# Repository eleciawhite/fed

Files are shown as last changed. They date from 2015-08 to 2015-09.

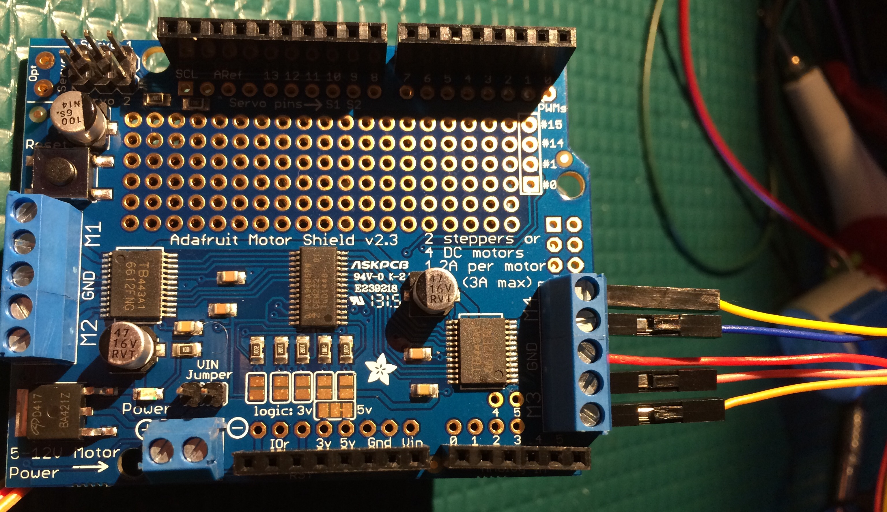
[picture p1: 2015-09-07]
doc/photos/motorShieldConnections.JPG

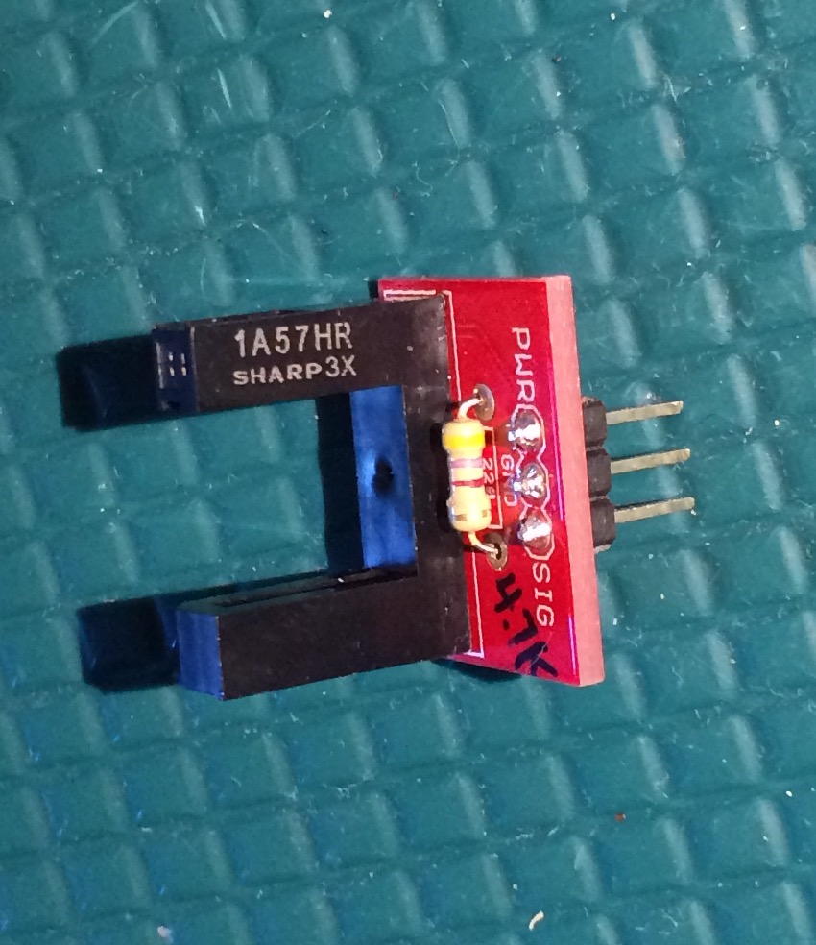
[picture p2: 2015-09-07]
doc/photos/irPhotoInterrupter.JPG

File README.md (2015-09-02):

# fed
Food Experimentation Device for precision feeding of mice. The system uses an Arduino processor, 
servo motor, IR beam detector, and SD card to log pellets taken. FED runs off of a battery. 

Please see the wiki page for more information, including build instructions: https://github.com/eleciawhite/fed/wiki

The hardware directory contains the system schematics. 
The mechanical pieces can be found on TinkerCAD (https://www.tinkercad.com/users/69Zt0NRn4eA-katrina-nguyen).
The software is in fed-arduino.

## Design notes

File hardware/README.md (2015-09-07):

Note that the FED schematics do not currently show the motor shield that is being used by the software.

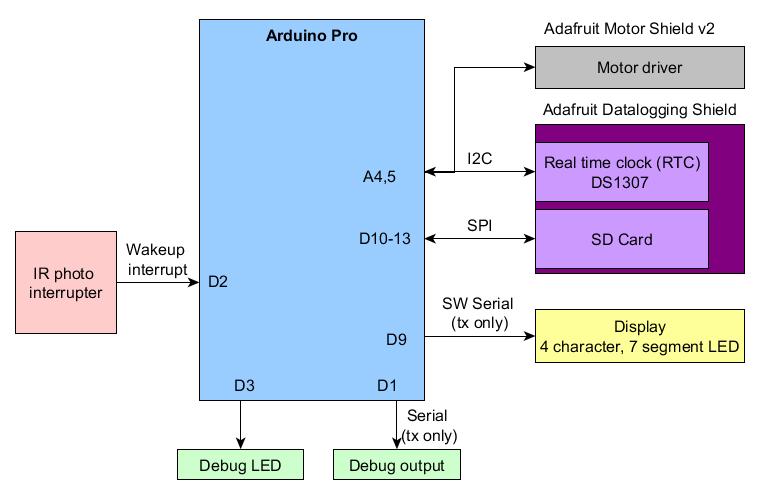
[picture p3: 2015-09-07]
doc/arduino-software-architecture.jpg

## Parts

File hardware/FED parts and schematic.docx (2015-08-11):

Electronics

1. Arduino Uno
2. Data logging shield for Arduino (Adafruit)
3. Small reduction stepper motor – 5VDC 32-step 1/16 gearing (Adafruit)
4. Dual h-bridge motor driver for DC or steppers – 600mA – L293D
5. Photo Interrupter board with GP1A57HRJ00f (Karlsson Robotics)
  a. GP1A57HRJ00f sensor (SHARP)
6. 7-segment serial display (SparkFun)

Circuit Schematic

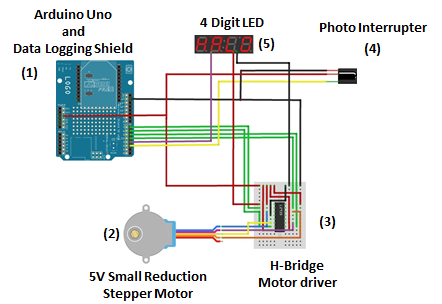
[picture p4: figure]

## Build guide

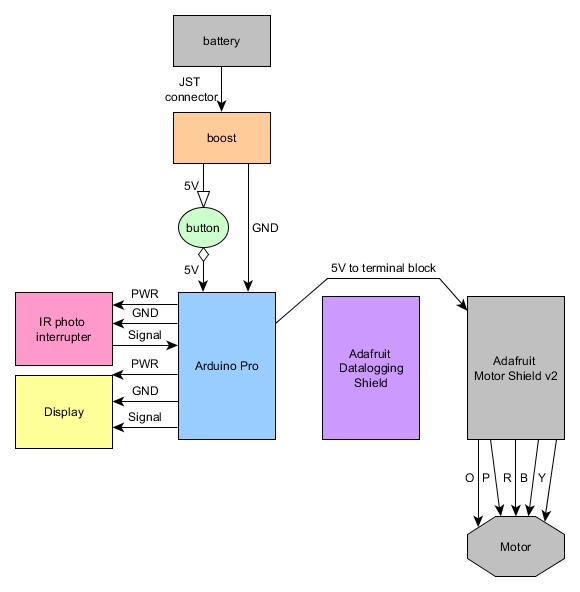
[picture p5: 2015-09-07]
doc/arduino-wiring-connection.jpg

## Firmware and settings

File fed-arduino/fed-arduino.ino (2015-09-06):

#include <avr/sleep.h>
#include <avr/power.h>
#include <avr/wdt.h>
#include <SdFat.h>                // SD and RTC libraries
#include "RTClib.h"
#include <Wire.h>
#include <SPI.h>
#include <Adafruit_GFX.h>
#include <Adafruit_SharpMem.h>
#include <avr/interrupt.h>
#include <avr/io.h>
#include <SoftwareSerial.h>
#include <Adafruit_MotorShield.h>
#include "utility/Adafruit_PWMServoDriver.h"

#define FILENAME "PELLET_Cage12.csv"

#define DISPLAY_SERIAL_RX_PIN 255 // we don't need a receive pin, 255 indicates this
// Connect the Arduino pin 3 to the rx pin on the 7 segment display
#define DISPLAY_SERIAL_TX_PIN 9

// Photo interrupter is also the wakeup for the system
#define PHOTO_INTERRUPTER_PIN 2

SoftwareSerial LEDserial = SoftwareSerial(DISPLAY_SERIAL_RX_PIN, DISPLAY_SERIAL_TX_PIN);
SdFat SD;

long previousMillis = 0;
long startTime = 0;
long timeElapsed = 0;
const long day2 = 86400000; // 86400000 milliseconds in a day
const long hour2 = 3600000; // 3600000 milliseconds in an hour
const long minute2 = 60000; // 60000 milliseconds in a minute
const long second2 =  1000; // 1000 milliseconds in a second

const int CS_pin = 10;
RTC_DS1307 RTC;    // refer to the real-time clock on the SD shield
String time;
File dataFile;

const int TTL_DEBUG_PIN = 3;

const int STEPS_TO_INCREMENT = 64;
const int MOTOR_STEPS_PER_REVOLUTION = 513;

int PIState = 1;
int lastState = 1;

int pelletCount = 0;

// Stepper motor with shield test
Adafruit_MotorShield gMotorShield = Adafruit_MotorShield();
Adafruit_StepperMotor *gPtrToStepper = gMotorShield.getStepper(MOTOR_STEPS_PER_REVOLUTION,2);

int logData() {
  String year, month, day, hour, minute, second;
  power_twi_enable();
  power_spi_enable();

  DateTime datetime = RTC.now();
  year = String(datetime.year(), DEC);
  month = String(datetime.month(), DEC);
  day  = String(datetime.day(),  DEC);
  hour  = String(datetime.hour(),  DEC);
  minute = String(datetime.minute(), DEC);
  second = String(datetime.second(), DEC);

  // concatenates the strings defined above into date and time
  time = month + "/" + day + " " + hour + ":" + minute + ":" + second;

  // opens a file on the SD card and prints a new line with the
  // current reinforcement schedule, the time stamp,
  // the number of sucrose deliveries, the number of active and
  // inactive pokes, and the number of drinking well entries.

  dataFile = SD.open(FILENAME, FILE_WRITE);
  if (dataFile) {
    Serial.println(F("File successfully written..."));
    Serial.println(time);
    dataFile.print(time);
    dataFile.print(",");
    dataFile.print(pelletCount);
    dataFile.print(",");
    dataFile.println(timeElapsed);
    dataFile.close();
  }
  power_twi_disable();
  power_spi_disable();
}

void setup()
{

  // make all unused pins inputs with pullups enabled by default, lowest power drain
  // leave pins 0 & 1 (Arduino RX and TX) as they are
  for (byte i=2; i <= 20; i++) {    
    pinMode(i, INPUT_PULLUP);     
  }
  ADCSRA = 0;  // disable ADC as we won't be using it
  power_adc_disable(); // ADC converter
  power_timer1_disable();// Timer 1
  power_timer2_disable();// Timer 2

  Serial.begin(9600);
  Serial.println(F("Starting up..."));

  // Display setup
  LEDserial.begin(9600); 
  pinMode(DISPLAY_SERIAL_TX_PIN, OUTPUT);
  setDisplayBrightness(64);
  clearDisplay();
  delay(1); // allow a very short delay for display response
  setDisplayValues(pelletCount);
  
  pinMode(PHOTO_INTERRUPTER_PIN, INPUT);
  pinMode(TTL_DEBUG_PIN, OUTPUT);
  pinMode(CS_pin, OUTPUT);
  pinMode(SS, OUTPUT);

  Wire.begin();
  
  // both the stepper control and RTC use I2C (the Wire library)
  RTC.begin(); // RTC library needs Wire

  // set up stepper
  gMotorShield.begin(); // use default I2C address of 0x40
  gPtrToStepper->setSpeed(30); // rpm, max suggested by Adafruit for this 5V stepper

  if (! RTC.isrunning()) {
    Serial.println(F("RTC is NOT running!"));
    // following line sets the RTC to the date & time this sketch was compiled
    RTC.adjust(DateTime(F(__DATE__), F(__TIME__)));
    // This line sets the RTC with an explicit date & time, for example to set
    // January 21, 2014 at 3am you would call:
    // rtc.adjust(DateTime(2014, 1, 21, 3, 0, 0));
  }

  if (!SD.begin(CS_pin)) {
    Serial.println(F("Card failed, or not present"));
    // don't do anything more:
    while (1) ;
  }

  Serial.println(F("Card initialized."));

  dataFile = SD.open("PELLETJuly.csv", FILE_WRITE);
  if (! dataFile) {
    Serial.println(F("Error opening datalog.txt"));
    // Wait forever since we cant write data
    while (1) ;
  }

  else {
    dataFile.print(time);
    dataFile.println(F("Time,Pellet Count,Pellet Drop Delay"));
    dataFile.close();
  }
    
  delay (500);
  
  // get ready for what the system should be doing
  PIState = digitalRead(PHOTO_INTERRUPTER_PIN);
  lastState = 0;
}

void loop()
{
  PIState = digitalRead(PHOTO_INTERRUPTER_PIN);
  Serial.print("Photointerrupter State: ");
  Serial.println(PIState);
  digitalWrite(TTL_DEBUG_PIN, LOW);

  if (PIState == 1  & PIState != lastState) {    
    digitalWrite(TTL_DEBUG_PIN, HIGH);    
    startTime = millis();
    Serial.print(F("Time Elapsed Check: "));
    Serial.println(timeElapsed);
    timecounter(timeElapsed);
    logData();
    pelletCount ++;
    Serial.println(F("It did work"));
    clearDisplay();
    delay(2); // allow a very short delay for display response
    setDisplayValues(pelletCount);
    lastState = PIState;
  }
  else if (PIState == 1) {
    Serial.println(F("Turning motor..."));
    power_twi_enable();
    gPtrToStepper->step(STEPS_TO_INCREMENT/2,FORWARD,DOUBLE);
    gPtrToStepper->step(STEPS_TO_INCREMENT,BACKWARD,DOUBLE);
    gPtrToStepper->release();
    power_twi_disable();
    lastState = PIState;
  }
  
  else if (PIState == 0 & PIState != lastState) {
    Serial.print(F("Time Elapsed Since Last Pellet: "));
    timeElapsed = millis() - startTime;
    Serial.println(timeElapsed);
    lastState = PIState;
  }
    
  else  {
    lastState = PIState;
    enterSleep();
  }
  
  delay(100);
}


void timecounter(long timeNow) {

  Serial.println(timeNow);
  int days = timeNow / day2 ;                                //number of days
  int hours = (timeNow % day2) / hour2;                       //the remainder from days division (in milliseconds) divided by hours, this gives the full hours
  int minutes = ((timeNow % day2) % hour2) / minute2 ;         //and so on...
  int seconds = (((timeNow % day2) % hour2) % minute2) / second2;
  int mil = ((((timeNow % day2) % hour2) % minute2) % second2);

  // digital clock display of current time
  printDigits(hours); Serial.print(":");
  printDigits(minutes); Serial.print(":");
  printDigits(seconds); Serial.print(":");
  printDigits(mil);
  Serial.println();

}

// utility function for digital clock display: prints colon and leading 0
void printDigits(byte digits) {
  if (digits < 10) {
    Serial.print('0');
  }
  Serial.print(digits, DEC);
}

void enterSleep()
{
  power_usart0_disable();// Serial (USART) 

  sleep_enable();

  attachInterrupt(0, pinInterrupt, RISING);
  lastState = 0;
  delay(100);

  set_sleep_mode(SLEEP_MODE_PWR_DOWN);   /* EDIT: could also use SLEEP_MODE_PWR_DOWN for lowest power consumption. */
  cli();
  sleep_bod_disable();
  sei();
  sleep_cpu();
  sleep_disable();
}

void pinInterrupt(void)
{
  detachInterrupt(0);

  /* The program will continue from here after the WDT timeout*/
  sleep_disable(); /* First thing to do is disable sleep. */

  /* Re-enable the serial. */
  power_usart0_enable();
}

// Send the clear display command (0x76)
//  This will clear the display and reset the cursor
void clearDisplay()
{
  LEDserial.write(0x76);  // Clear display command
}

// Set the displays brightness. Should receive byte with the value
//  to set the brightness to
//  dimmest------------->brightest
//     0--------127--------255
void setDisplayBrightness(byte value)
{
  LEDserial.write(0x7A);  // Set brightness command byte
  LEDserial.write(value);  // brightness data byte
}

void setDisplayValues(int value)
{
  LEDserial.print(value);
}

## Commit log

2015-08-11 Initial files from Lex and Kat
    [FED Schematic.fzz]
2015-08-13 Added motor control to reduce current draw by ~24mA
2015-08-19 Katrina updated for current system: button, LED representing serial out, new motor control lines to processor.
    [FED Schematic.fzz]
2015-08-25 Stuck at 37mA sleep current with Arduino Pro (blue display, always on, and 4.7k ohm on interrupter)
    [fed-arduino.ino]
2015-08-25 Power subsystems on and off as needed.
2015-08-25 Move motor control pin so it doesn't interfere with the SPI lines used by the SD card.
    [fed-arduino.ino]
2015-09-01 Moved output filename name up to start Fixed bug with initial condition on the motor
    [fed-arduino.ino]
2015-09-06 Switch to using the Adafruit motor shield (v2.3). It is I2C based so uses fewer GPIO but that means twi must be left on.
2015-09-07 Updated docs to use Adafruit motor shield
2015-09-07 Added hardware readme with out-of-date notice and wiring diagram
